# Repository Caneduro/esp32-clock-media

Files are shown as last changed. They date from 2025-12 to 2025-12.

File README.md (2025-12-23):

## **Tiny Wi-Fi Clock / Media Display**
   A compact 3D-printed desk gadget that displays the time or, with a press of the **on-board BOOT button**, switches to show your PC’s current media activity (received via Wi-Fi from a small Python script).\
   The enclosure is printed in **three PLA parts** (front, middle, back) assembled with **heat inserts and screws** for a solid, serviceable build.\
   It prints in about **1 hour** and uses only **~14 g of PLA** — perfect for a quick and satisfying build.
   ### **Features**
- 🕒 Clean, high-contrast oled **time** display
- 🎵 **Media** mode with track info, progress, duration, play/pause status, volume, scrolling if text too long
- 📡 Wi-Fi6 communication with a simple Python script on your PC
- 🔘 Uses the **on-board BOOT button** — no external switch needed 
- 🧱 3-part enclosure with heat inserts + M2 screws
- ⚡ USB type C connection 
### **Print Details**
- 🧵 **Material:** PLA (~14 g)
- ⏱ **Print time:** ~1 hour
- 🧩 **Included 3MF parts:** front (screen cover), middle (electronics housing), rear
### **Bill of Materials**
Here are the exact components used in the build:

- 🔌 **ESP32-C6 SuperMini development board (USB-C)**\
  [https://it.aliexpress.com/item/1005009279209835.html](https://it.aliexpress.com/item/1005009279209835.html)
- 🖥️ **128×64 0.96″ monochrome white OLED display**\
  [https://it.aliexpress.com/item/1005006141235306.html](https://it.aliexpress.com/item/1005006141235306.html)
- 🔩 **M2 brass heat inserts + M2 screws** \
  [https://it.aliexpress.com/item/1005007615031481.html](https://it.aliexpress.com/item/1005007615031481.html)
- 📌 **Solder-pin headers (to connect the OLED via jumper wires)**\
  [https://it.aliexpress.com/item/4000875355189.html](https://it.aliexpress.com/item/4000875355189.html)
- 🧵 **Female-to-female jumper cables**\
  [https://it.aliexpress.com/item/1005003641187997.html](https://it.aliexpress.com/item/1005003641187997.html)

## **How to Flash the Code to the ESP32-C6 SuperMini**
Follow these steps to upload the firmware to your ESP32-C6 using the Arduino IDE.
### **🔧 1. Install the required tools**
1. Download and install the **Arduino IDE** (version 2.x recommended).
1. Open the IDE, go to **File → Preferences**.
1. In *Additional Boards Manager URLs*, add this URL (if not already present):

*`https://raw.githubusercontent.com/espressif/arduino-esp32/gh-pages/package_esp32_index.json`*

1. Go to **Tools → Board → Boards Manager** and search for:\
   **“ESP32 by Espressif Systems”**\
   → Install it (or update to the latest version).
1. Install any required libraries for your project (e.g. WiFi, SSD1306 display, etc., depending on your code, they are usually on top).
### **🔌 2. Connect the ESP32-C6 to your PC**
- Plug the board into your computer using a **USB-C cable** (ensure it’s a data cable, not charge-only).
- The board should appear as a COM/serial port or it should be recognized as ESP32 Family Device then select the appropriate device.
### **🧭 3. Select the correct board**
In Arduino IDE:

- Go to **Tools → Board → ESP32**
- Select **“ESP32C6 Dev Module”** (or “ESP32-C6 SuperMini” if shown).
### **🔌 4. Select the right serial port**
- Go to **Tools → Port**
- Choose the port labeled **ESP32C6** or the newly appeared COM port.

If you’re unsure which one is correct:

- Unplug the board → check the list
- Plug it back → choose the new entry that appears.
### **📄 5. Load your project code**
- Open the .ino file (or create a new sketch and paste your code).
- Go to **Sketch** and click **Add file…** to add the fonts **(THIS IS MANDATORY)**

- Verify that any required libraries are installed otherwise it will give out error (the error shows wich library is missing).
### **📝 6. Adjust upload settings** 
Usually the defaults work, but for ESP32-C6 ensure:

- **Tools → Upload Speed:** 115200 (safe default)
- **Tools → USB CDC On Boot:** Enabled

- **Tools → Partition Scheme: Minimal SPIFFS (otherwise ota update will not work)**
### **⬇️ 7. Put the board into bootloader mode (if required)**
Often the ESP32-C6 enters bootloader mode automatically.\
If flashing fails on the first attempt:

1. Hold **BOOT**
1. Click **RESET** (if present on your module)
1. Release **BOOT** after 1–2 seconds

Then try uploading again.

Most C6 SuperMini boards auto-reset and you won’t need this step.
### **🚀 8. Upload the code**
- Click the **Upload** button (the right-arrow icon).
- Wait for compilation and flashing to complete.
- The serial monitor will confirm a successful upload.
### **✔️ 9. Test the device**
- Open **Serial Monitor** (Tools → Serial Monitor) to check Wi-Fi logs or debug messages.
- If using your BOOT button to toggle modes, verify it responds correctly once the device is running., 

### **BUILDING INSTRUCTIONS**

- Print the the file (1 part at a time or all at once as you prefer)

- use your preferred method to put all the heat inserts: 
  - face: M2 x 3mm         - screw: M2 x 7mm (at least more than 3mm)
  - rear: M2 x 2mm         - screw: M2 x 6mm (at least more than 2mm)

- solder 4 header pins (gnd - 3v3 - 20 -19) 

- connect to screen with jumper cables: 

   - gnd with gnd

   - 3v3 with 3v3 

   - pin 20 with SCK

   - pin 19 with SDA

- "coil" the cable to fit all inside the enclosure

- put the screen over the holes from the front and put the face 3d printed part over it then screw them to keep it in place

- put the rear cover and screw it in place 

**FULLY OPEN-SOURCE\
All required files — firmware, the Python script, and all 3D models — are available on GitHub:\
👉 https://github.com/caneduro/esp32-clock-media**
----------------------------------------------------------------------------------------------
The project is fully **open-source**.\
Anyone can fork it, modify it, improve it, or contribute.\
The current version is not 100% complete and can definitely be refined by someone with more experience — contributions are welcome!
BTW right now all the text are in italian, so you need to change them to be your language + YOU NEED TO CHANGE WIFI CREDENTIALS OTHERWISE IT WON'T WORK AND OTA (if you need to)

3D model view
3D view

Front view with clock
clock front view

Front view witch media
media front view

Back internal view
Back hollow

Internal view
Internal view

ToDo list
- [x] Update Python code to fix volume and postition (Note: when changing volume the song position may change temporarily idky)
- [ ] Update C code to implement WiFi captive portal to connect instead of hardcoded wifi ssid and password
- [ ] Add small clock on top of the Media mode (maybe with some animation changing from clock to media and vice versa) (so you could have clock on media mode but idk if the single core ESP32C6 could handle it)
- [ ] Improve reactivity of the infos on Media mode (python side i think)
- [ ] Think about adding a battery inside the casing or maybe another "battery module" that could be added behind with usb c
- [ ] switch from screws and heat inserts to small magnets (maybe???)

If you want to help, you can talk to me on my discord
[discordhereeee!!!](https://discord.gg/QAPAbSd2Ep)

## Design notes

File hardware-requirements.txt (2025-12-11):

ESP32-C6 Supermini dev board usb C
4 solder pins (used to connect the screen with cables to the esp32)
8 brass heat insert 
8 screws:
			face: M2 x 3mm 		screw: M2 x 7mm (at least more than 3mm)
			rear: M2 x 2mm 		screw: M2 x 6mm (at least more than 2mm)	
1,5mm Hex Key (to screw in the screws, you can also use the one wich comes with your 3d printer like A1 mini etc.. lol)			
1 OLED SCREEN 128x64 px (i used an all white pixel one)
4 dupont female-female cables (i used 10cm but i think less would be better) 
13g of PLA and around 1H of your time ;)

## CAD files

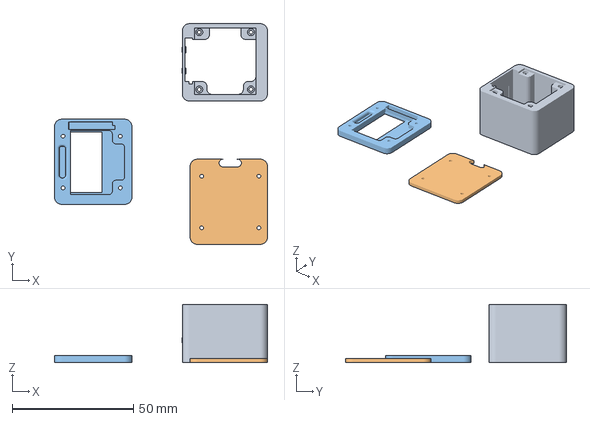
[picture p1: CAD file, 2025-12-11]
MINI Esp32 usb clock v9.3mf
88.0 x 91.2 x 24.1 mm
Corpo2
Corpo1 x 2

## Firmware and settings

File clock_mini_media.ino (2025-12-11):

// merged_clock_media_button_idle_auto_switch_fixed.ino
// Merge: clock (Adafruit) + media (U8g2).
// Fix: scrolling bug, robust manual toggle after auto-switch, reset media to defaults in a function.

#include <WiFi.h>
#include <NTPClient.h>
#include <WiFiUdp.h>

#include <Wire.h>
#include <Adafruit_GFX.h>
#include <Adafruit_SSD1306.h>

#include <U8g2lib.h>

#include <WebServer.h>
#include <ArduinoJson.h>

#include "unifont_custom.h" 

#include <ArduinoOTA.h>
//#include <ElegantOTA.h>


// -------------------- CONFIG --------------------
#define SCREEN_WIDTH 128
#define SCREEN_HEIGHT 64
#define OLED_SDA 19
#define OLED_SCL 20

U8G2_SSD1306_128X64_NONAME_F_HW_I2C u8g2(U8G2_R0, U8X8_PIN_NONE);
Adafruit_SSD1306 display(SCREEN_WIDTH, SCREEN_HEIGHT, &Wire, -1);

const char* ssid = "YOURWIFI";
const char* password = "YOURPASSWORD";
WiFiUDP ntpUDP;
NTPClient timeClient(ntpUDP, "pool.ntp.org", 3600, 60000);

WebServer server(80);

const char* otahostname = "ESP32-OTA";
const char* otapassword = "yourpassword";

// Debug
const bool DEBUG_SERIAL = false;

// -------------------- CLOCK (Adafruit) resources --------------------
#include <Fonts/FreeSans9pt7b.h>
#include <Fonts/FreeSans12pt7b.h>
#include <Fonts/FreeSans18pt7b.h>
#include <Fonts/FreeSans24pt7b.h>
#include <Fonts/FreeSansBold9pt7b.h>
#include <Fonts/FreeSansBold12pt7b.h>
#include <Fonts/FreeSansBold18pt7b.h>
#include <Fonts/FreeSansBold24pt7b.h>
#include <Fonts/FreeSerif9pt7b.h>
#include <Fonts/FreeSerif12pt7b.h>
#include <Fonts/FreeSerif18pt7b.h>
#include <Fonts/FreeSerif24pt7b.h>
#include <Fonts/FreeMono9pt7b.h>
#include <Fonts/FreeMono12pt7b.h>
#include <Fonts/FreeMono18pt7b.h>
#include <Fonts/FreeMono24pt7b.h>

const char* giorniArr[] = {"dom", "lun", "mar", "mer", "gio", "ven", "sab"};
const char* mesiArr[]  = {"gen","feb","mar","apr","mag","giu","lug","ago","set","ott","nov","dic"};

const GFXfont* fontsArr[] = {
  nullptr,
  &FreeSans9pt7b, &FreeSans12pt7b, &FreeSans18pt7b, &FreeSans24pt7b,
  &FreeSansBold9pt7b, &FreeSansBold12pt7b, &FreeSansBold18pt7b, &FreeSansBold24pt7b,
  &FreeSerif9pt7b, &FreeSerif12pt7b, &FreeSerif18pt7b, &FreeSerif24pt7b,
  &FreeMono9pt7b, &FreeMono12pt7b, &FreeMono18pt7b, &FreeMono24pt7b
};
const int numFonts = sizeof(fontsArr) / sizeof(fontsArr[0]);

int fontOrologio = 8;
int fontSecondi  = 0;
int fontData     = 0;
int dimensioneOrologio = 4;
int dimensioneSecondi  = 1;
int dimensioneData     = 1;

int posizioneYOrologio = 35;
int posizioneYSecondi  = 39;
int posizioneYData     = SCREEN_HEIGHT - 12;

unsigned long lastSecond = 0;
unsigned long lastWifiAttempt = 0;
bool wifiConnected = false;
const unsigned long wifiRetryInterval = 400; // ms

// clock state
int hours = 0;
int minutes = 0;
int seconds = 0;
int day = 1;
int month = 1;
int year = 1970;
int dayOfWeek = 4;

// -------------------- MEDIA (U8g2) resources --------------------
const char* HOST_PATH = "/update";
#define USE_CUSTOM_UNIFONT 1
#define CUSTOM_UNIFONT_SYMBOL unifont_custom
#define USE_UNIFONT_FOR_POSITION 1
#define USE_UNIFONT_FOR_VOLUME   1

const int GAP_PIXELS = 30;
const unsigned long SCROLL_STEP_MS = 30;

String mediaTitle = "Nessun titolo";
String mediaArtist = "Nessun artista";
String mediaStatus = "PAUSE";

float serverPosition = 0.0f;
float displayPosition = 0.0f;
float mediaDuration = 0.0f;
unsigned long lastServerMillis = 0;

float mediaProgress = 0.0f;
float targetProgress = 0.0f;
float mediaVolume = 0.0f;
float targetVolume = 0.0f;

int scrollOffsetTitle = 0;
int scrollOffsetArtist = 0;
unsigned long lastScrollMs = 0; 

const int ICON_W = 18;
const int TEXT_AREA_X = ICON_W + 2;
const int TEXT_AREA_RIGHT_MARGIN = 12;
const int TEXT_AREA_W = 128 - TEXT_AREA_X - TEXT_AREA_RIGHT_MARGIN;

const float staleThreshold = 0.5f;
const float seekThreshold  = 1.0f;

// -------------------- MODE / BUTTON --------------------
#define BOOT_BUTTON_PIN 9
enum Mode { MODE_MEDIA=0, MODE_CLOCK=1 };
volatile Mode currentMode = MODE_CLOCK;

// ISR flag + guard
volatile bool buttonISRflag = false;
unsigned long lastToggleMillis = 0;
const unsigned long TOGGLE_GUARD_MS = 200;

// -------------------- IDLE/AUTO-SWITCH --------------------
const unsigned long MEDIA_IDLE_TIMEOUT_MS_DEFAULT = 5UL * 60UL * 1000UL; // 5 minutes
unsigned long MEDIA_IDLE_TIMEOUT_MS = MEDIA_IDLE_TIMEOUT_MS_DEFAULT;

// last time we had media activity (update received, position advanced, volume changed...)
// initialized in setup
unsigned long lastMediaActiveMs = 0;

// to detect movement
float prevDisplayPosition = -1.0f;
const float MOVEMENT_EPS = 0.25f; // seconds movement threshold to consider "activity"

// protect auto-switch briefly after manual toggle so user can open MEDIA without instant re-auto-switch
unsigned long manualProtectUntil = 0;
const unsigned long MANUAL_PROTECT_MS = 2000UL; // 2 seconds

// -------------------- HELPERS --------------------
String formatTimeMMSS(int secondsVal){
  int m = secondsVal / 60;
  int s = secondsVal % 60;
  char buf[16];
  snprintf(buf, sizeof(buf), "%02d:%02d", m, s);
  return String(buf);
}

// reset media values in one place (reusable)
void resetMediaStateToDefaults(bool keepLastMediaActive = false){
  mediaTitle = "Nessun titolo";
  mediaArtist = "Nessun artista";
  mediaStatus = "PAUSE";
  serverPosition = 0.0f;
  displayPosition = 0.0f;
  mediaDuration = 0.0f;
  lastServerMillis = millis();
  mediaProgress = 0.0f;
  targetProgress = 0.0f;
  mediaVolume = 0.0f;
  targetVolume = 0.0f;
  scrollOffsetTitle = 0;
  scrollOffsetArtist = 0;
  prevDisplayPosition = -1.0f;
  if (!keepLastMediaActive) {
    // caller decides whether to update lastMediaActiveMs
    // normally when auto-switching we won't preserve lastMediaActive
  }
}

// -------------------- CLOCK (Adafruit) functions --------------------
void impostaFontClock(int fontIndex, int dimensione) {
  if (fontIndex >= 0 && fontIndex < numFonts) {
    if (fontsArr[fontIndex] == nullptr) {
      display.setFont(); // default
      display.setTextSize(dimensione);
    } else {
      display.setFont(fontsArr[fontIndex]);
      display.setTextSize(1);
    }
  } else {
    display.setFont();
    display.setTextSize(dimensione);
  }
}

void updateDisplayClock(){
  display.clearDisplay();

  impostaFontClock(fontOrologio, dimensioneOrologio);
  String timeStr = (hours < 10 ? "0" : "") + String(hours) + ":" + (minutes < 10 ? "0" : "") + String(minutes);

  int16_t x1,y1; uint16_t w,h;
  display.getTextBounds(timeStr, 0, 0, &x1, &y1, &w, &h);
  int xTime = (SCREEN_WIDTH - w) / 2;
  display.setCursor(xTime, posizioneYOrologio);
  display.setTextColor(WHITE);
  display.print(timeStr);

  // secondi
  impostaFontClock(fontSecondi, dimensioneSecondi);
  String secStr = (seconds < 10 ? "0" : "") + String(seconds);
  display.getTextBounds(secStr, 0, 0, &x1, &y1, &w, &h);
  display.setCursor(SCREEN_WIDTH - w - 2, posizioneYSecondi);
  display.print(secStr);

  // data
  impostaFontClock(fontData, dimensioneData);
  String dataStr = String(giorniArr[dayOfWeek]) + " " + String(day) + " " + String(mesiArr[month-1]) + " " + String(year);
  display.getTextBounds(dataStr, 0, 0, &x1, &y1, &w, &h);
  int xData = (SCREEN_WIDTH - w) / 2;
  display.setCursor(xData, posizioneYData);
  display.print(dataStr);

  // linea separatrice
  display.drawLine(0, SCREEN_HEIGHT - 15, SCREEN_WIDTH, SCREEN_HEIGHT - 15, WHITE);

  display.display();

  if (DEBUG_SERIAL) {
    Serial.print("[DEBUG] Clock draw: ");
    Serial.print(timeStr); Serial.print(" "); Serial.println(dataStr);
  }
}

// -------------------- MEDIA (U8g2) functions --------------------
void drawStateIcon_u8(){
  const int x = 0, y = 0, w = ICON_W, h = 18;
  u8g2.setDrawColor(0);
  u8g2.drawBox(x,y,w,h);
  u8g2.setDrawColor(1);
  if(mediaStatus == "PLAY"){
    int x1 = x+4, y1 = y+3;
    int x2 = x+4, y2 = y+15;
    int x3 = x+14, y3 = y+9;
    u8g2.drawTriangle(x1,y1,x2,y2,x3,y3);
  } else {
    int barW=3,gap=4,bx=x+4,by=y+3,bh=12;
    u8g2.drawBox(bx,by,barW,bh);
    u8g2.drawBox(bx+barW+gap,by,barW,bh);
  }
}

void drawVolume_u8(){
  int barWidth=6, barHeight=16, barX=128-barWidth, barY=0;
  u8g2.setDrawColor(0);
  u8g2.drawBox(barX,barY,barWidth,barHeight);
  u8g2.setDrawColor(1);
  int volHeight = (int)constrain((mediaVolume/100.0f)*barHeight, 0, barHeight);
  u8g2.drawFrame(barX,barY,barWidth,barHeight);
  u8g2.drawBox(barX, barY + barHeight - volHeight, barWidth, volHeight);
  if(USE_UNIFONT_FOR_VOLUME) u8g2.setFont(CUSTOM_UNIFONT_SYMBOL);
  else u8g2.setFont(u8g2_font_6x10_tr);
  String volStr = String((int)(mediaVolume + 0.5f));
  int numW = u8g2.getUTF8Width(volStr.c_str());
  int xOffset = barX - numW - 2;
  int yOffset = USE_UNIFONT_FOR_VOLUME ? (10 + 6) : ((barHeight - 6) / 2 + 6);
  u8g2.drawUTF8(xOffset, yOffset, volStr.c_str());
}

void drawProgressBar_u8(){
  int barWfilled = (int)((mediaProgress / 100.0f) * 128.0f);
  barWfilled = constrain(barWfilled, 0, 128);
  u8g2.setDrawColor(1);
  u8g2.drawBox(0, 64 - 8, barWfilled, 4);
  u8g2.drawFrame(0, 64 - 8, 128, 4);
  if(USE_UNIFONT_FOR_POSITION) u8g2.setFont(CUSTOM_UNIFONT_SYMBOL);
  else u8g2.setFont(u8g2_font_6x10_tr);
  u8g2.drawUTF8(0, 64 - 16 + 6, formatTimeMMSS((int)displayPosition).c_str());
  String tot = formatTimeMMSS((int)mediaDuration);
  int len = u8g2.getUTF8Width(tot.c_str());
  u8g2.drawUTF8(128 - len, 64 - 16 + 6, tot.c_str());
}

void drawScrollingUTF8_u8(const String &txt, int baselineY, int areaX, int areaW, int &offset){
  const char* s = txt.c_str();
#if USE_CUSTOM_UNIFONT
  u8g2.setFont(CUSTOM_UNIFONT_SYMBOL);
#else
  u8g2.setFont(u8g2_font_unifont_t_symbols);
#endif
  uint16_t textW = u8g2.getUTF8Width(s);
  if(textW <= (uint16_t)areaW){
    u8g2.drawUTF8(areaX, baselineY, s);
    offset = 0;
  } else {
    int total = textW + GAP_PIXELS;
    int x1 = areaX - offset;
    int x2 = x1 + total;
    u8g2.drawUTF8(x1, baselineY, s);
    u8g2.drawUTF8(x2, baselineY, s);
  }
}

void updateDisplayMedia(){
  u8g2.clearBuffer();
  drawStateIcon_u8();
  drawVolume_u8();
  int titleBaseline = 27;
  int artistBaseline = 41;
  drawScrollingUTF8_u8(mediaTitle, titleBaseline, TEXT_AREA_X, TEXT_AREA_W, scrollOffsetTitle);
  drawScrollingUTF8_u8(mediaArtist, artistBaseline, TEXT_AREA_X, TEXT_AREA_W, scrollOffsetArtist);
  drawProgressBar_u8();
  u8g2.sendBuffer();
}

// scrollTick_u8 is now self-contained: it updates lastScrollMs and offsets
void scrollTick_u8(){
  unsigned long now = millis();
  if(now - lastScrollMs < SCROLL_STEP_MS) return;
  lastScrollMs = now;

#if USE_CUSTOM_UNIFONT
  u8g2.setFont(CUSTOM_UNIFONT_SYMBOL);
#else
  u8g2.setFont(u8g2_font_unifont_t_symbols);
#endif

  uint16_t wTitle = u8g2.getUTF8Width(mediaTitle.c_str());
  if(wTitle > (uint16_t)TEXT_AREA_W){
    int total = wTitle + GAP_PIXELS;
    scrollOffsetTitle++;
    if(scrollOffsetTitle >= total) scrollOffsetTitle = 0;
  } else scrollOffsetTitle = 0;

  uint16_t wArtist = u8g2.getUTF8Width(mediaArtist.c_str());
  if(wArtist > (uint16_t)TEXT_AREA_W){
    int total = wArtist + GAP_PIXELS;
    scrollOffsetArtist++;
    if(scrollOffsetArtist >= total) scrollOffsetArtist = 0;
  } else scrollOffsetArtist = 0;
}

// -------------------- MEDIA HTTP handler --------------------
void handleMediaUpdate(){
  if(DEBUG_SERIAL) Serial.println("[DEBUG] Received /update request");
  if(!server.hasArg("plain")){
    server.send(400, "application/json", "{\"status\":\"no body\"}");
    if(DEBUG_SERIAL) Serial.println("[DEBUG] No body in request");
    return;
  }
  String body = server.arg("plain");
  if(DEBUG_SERIAL){
    Serial.print("[DEBUG] Body: ");
    Serial.println(body);
  }

  JsonDocument doc;
  DeserializationError error = deserializeJson(doc, body);
  if(error){
    server.send(400, "application/json", "{\"status\":\"json error\"}");
    if(DEBUG_SERIAL) {
      Serial.print("[DEBUG] JSON parse error: ");
      Serial.println(error.c_str());
    }
    return;
  }

  String newTitle = doc["title"] | "Sconosciuto";
  String newArtist = doc["artist"] | "Sconosciuto";
  String newStatus = doc["status"] | "PAUSE";

  // normalize artists (basic)
  newArtist.replace(";", ",");
  newArtist.replace("|", ",");
  newArtist.replace("/", ",");
  while (newArtist.indexOf(",,") != -1) newArtist.replace(",,", ",");
  newArtist.replace(", ", ",");
  newArtist.replace(" ,", ",");
  newArtist.trim();

  float newPosition = 0.0f;
  float newDuration = 0.0f;
  int newVolume = -1;

  if (!doc["position"].isNull()) {
    newPosition = (float)doc["position"].as<double>();
  }
  if (!doc["duration"].isNull()) {
    newDuration = (float)doc["duration"].as<double>();
  }
  if (!doc["volume"].isNull()) {
    newVolume = doc["volume"].as<int>();
  }

  bool changed = false;
  unsigned long now = millis();

  // any received update is media activity -> reset idle timer
  lastMediaActiveMs = now;

  bool titleArtistChanged = (newTitle != mediaTitle) || (newArtist != mediaArtist);
  bool durationChanged = fabs(newDuration - mediaDuration) > 0.5f;

  if(titleArtistChanged || durationChanged){
    mediaTitle = newTitle;
    mediaArtist = newArtist;
    mediaDuration = newDuration;
    serverPosition = newPosition;
    lastServerMillis = now;
    displayPosition = serverPosition;
    targetProgress = (mediaDuration > 0.0f) ? (displayPosition * 100.0f / mediaDuration) : 0.0f;
    mediaProgress = targetProgress;
    mediaStatus = newStatus;
    if(newVolume >= 0) { targetVolume = (float)newVolume; mediaVolume = targetVolume; }
    scrollOffsetTitle = 0;
    scrollOffsetArtist = 0;
    changed = true;
  } else {
    if(newStatus != mediaStatus){ mediaStatus = newStatus; changed = true; }
    if(newTitle != mediaTitle || newArtist != mediaArtist){ mediaTitle = newTitle; mediaArtist = newArtist; changed = true; }

    if (mediaStatus == "PLAY") {
      float currentEstimate = serverPosition + ((now - lastServerMillis) / 1000.0f);
      float diff = newPosition - currentEstimate;
      if (fabs(diff) >= seekThreshold) {
        serverPosition = newPosition;
        lastServerMillis = now;
        changed = true;
      } else if (newPosition >= currentEstimate - staleThreshold) {
        serverPosition = newPosition;
        lastServerMillis = now;
        changed = true;
      } else {
        serverPosition = currentEstimate;
        lastServerMillis = now;
      }
    } else {
      serverPosition = newPosition;
      lastServerMillis = now;
      changed = true;
    }

    if (fabs(newDuration - mediaDuration) > 0.0001f) {
      mediaDuration = newDuration;
      changed = true;
    }

    // update volume even if title is default (fix missing volume update)
    if(newVolume >= 0 && newVolume != (int)targetVolume){
      targetVolume = (float)newVolume;
      changed = true;
    }
  }

  if(changed && currentMode == MODE_MEDIA) updateDisplayMedia();

  server.send(200, "application/json", "{\"status\":\"ok\"}");
  if(DEBUG_SERIAL) Serial.println("[DEBUG] /update processed, status ok");
}


//----------------------ota setup ------------------------------
void OTASetup(){ 
    ArduinoOTA.setHostname(otahostname);
    ArduinoOTA.setPassword(otapassword);
    ArduinoOTA
      .onStart([]() {
        String type;
        if (ArduinoOTA.getCommand() == U_FLASH)
         type = "sketch";
        else
          type = "filesystem";
       Serial.println("[OTA] Start updating " + type);
      })
      .onEnd([]() {
        Serial.println("\n[OTA] End");
      })
      .onProgress([](unsigned int progress, unsigned int total) {
        Serial.printf("[OTA] Progress: %u%%\r", (progress / (total / 100)));
      })
      .onError([](ota_error_t error) {
        Serial.printf("[OTA] Error[%u]: ", error);
        if (error == OTA_AUTH_ERROR) Serial.println("Auth Failed");
        else if (error == OTA_BEGIN_ERROR) Serial.println("Begin Failed");
        else if (error == OTA_CONNECT_ERROR) Serial.println("Connect Failed");
        else if (error == OTA_RECEIVE_ERROR) Serial.println("Receive Failed");
        else if (error == OTA_END_ERROR) Serial.println("End Failed");
      });
    
      ArduinoOTA.begin();
      //Serial.println("[OTA] Ready: access via http://" + WiFi.localIP().toString() + "/otaupdate");       //used for elegantOT, not in use right now
}

// -------------------- WiFi/NTP helpers --------------------
void connectToWiFi(){
  if(DEBUG_SERIAL) Serial.println("Tentativo di connessione WiFi...");
  //WiFi.setAutoReconnect(true);  i don't think it is needed??
  //WiFi.persistent(true);        i don't think it is needed??
  WiFi.begin(ssid, password);


  unsigned long startTime = millis();
  while (WiFi.status() != WL_CONNECTED && millis() - startTime < 1600) {
    delay(200);
    Serial.print(".");
  }

  if (WiFi.status() == WL_CONNECTED) {
    if(DEBUG_SERIAL){
      Serial.println("\Wi-Fi Connected!");
      Serial.print("IP address: ");
      Serial.println(WiFi.localIP());
    }
    wifiConnected = true;
    timeClient.begin();
  } else {
    if(DEBUG_SERIAL) Serial.println("\nWi-Fi connection failed!");
    wifiConnected = false;
  }
  lastWifiAttempt = millis();
}

// -------------------- Button ISR --------------------
void IRAM_ATTR bootButtonISR(){
  buttonISRflag = true;
}
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
void loop(){
  // Always service web server
  server.handleClient();

  ArduinoOTA.handle();

  unsigned long now = millis();

  // handle button ISR flag (debounced guard)
  if (buttonISRflag) {
    if (now - lastToggleMillis > TOGGLE_GUARD_MS) {
      Mode prev = currentMode;
      currentMode = (currentMode == MODE_MEDIA) ? MODE_CLOCK : MODE_MEDIA;
      lastToggleMillis = now;

      // if user manually opens MEDIA, protect from immediate auto-switch:
      if (currentMode == MODE_MEDIA) {
        lastMediaActiveMs = now; // protect for idle timeout
        prevDisplayPosition = -1.0f;
        manualProtectUntil = now + MANUAL_PROTECT_MS; // protect auto-switch briefly
        if (DEBUG_SERIAL) Serial.println("[DEBUG] Manual toggle -> set lastMediaActiveMs to now and protection");
      }

      if (DEBUG_SERIAL) {
        Serial.print("[DEBUG] Button toggled: ");
        Serial.print(prev==MODE_MEDIA ? "MEDIA" : "CLOCK");
        Serial.print(" -> ");
        Serial.println(currentMode==MODE_MEDIA ? "MEDIA" : "CLOCK");
      }

      if (currentMode == MODE_MEDIA) updateDisplayMedia();
      else updateDisplayClock();
    } else {
      if (DEBUG_SERIAL) Serial.println("[DEBUG] ISR guard: ignored");
    }
    buttonISRflag = false;
  }

  // WiFi reconnect attempt (non-blocking)
  if (!wifiConnected && (now - lastWifiAttempt > wifiRetryInterval)) {
    if (DEBUG_SERIAL) Serial.println("[DEBUG] Trying reconnect WiFi...");
    connectToWiFi();
  }

  if (currentMode == MODE_MEDIA) {
    // scroll tick: call the self-contained function (it internally throttles using lastScrollMs)
    scrollTick_u8();

    // update displayPosition estimation
    if(mediaStatus == "PLAY" && mediaDuration > 0.0f){
      float elapsed = (float)(now - lastServerMillis) / 1000.0f;
      displayPosition = serverPosition + elapsed;
      if(displayPosition > mediaDuration) displayPosition = mediaDuration;
    } else {
      displayPosition = serverPosition;
    }

    // detect movement (activity)
    if(prevDisplayPosition < 0.0f) {
      prevDisplayPosition = displayPosition;
    } else {
      if (fabs(displayPosition - prevDisplayPosition) > MOVEMENT_EPS) {
        lastMediaActiveMs = now;
      }
      prevDisplayPosition = displayPosition;
    }

    // easing updates
    targetProgress = (mediaDuration > 0.0f) ? (displayPosition * 100.0f / mediaDuration) : 0.0f;
    const float easing = 0.21f;
    mediaProgress += (targetProgress - mediaProgress) * easing;
    mediaVolume  += (targetVolume - mediaVolume) * easing;

    // throttle actual redraw to reduce CPU
    static unsigned long lastMediaDrawMs = 0;
    const unsigned long MEDIA_DRAW_MS = 16; // ~60 FPS
    if (now - lastMediaDrawMs >= MEDIA_DRAW_MS) {
      lastMediaDrawMs = now;
      updateDisplayMedia();
    }

    // AUTO-SWITCH: guard manual protection, then if no activity for configured timeout -> switch to clock
    if (now < manualProtectUntil) {
      // still in protection window after manual toggle; do NOT auto-switch
    } else {
      if ((now - lastMediaActiveMs) >= MEDIA_IDLE_TIMEOUT_MS) {
        if (currentMode == MODE_MEDIA) {
          currentMode = MODE_CLOCK;
          // reset media state to defaults (as requested)
          resetMediaStateToDefaults();
          // IMPORTANT: set lastMediaActiveMs to now so we don't immediately flip back
          lastMediaActiveMs = now;
          if (DEBUG_SERIAL) {
            Serial.println("[DEBUG] Auto-switch to CLOCK due to media idle. Media state reset to defaults.");
          }
          updateDisplayClock();
        }
      }
    }

  } else {
    // CLOCK mode - update at most once per second
    static unsigned long lastClockDrawMs = 0;
    if (wifiConnected) {
      timeClient.update(); // lightweight
      if (now - lastClockDrawMs >= 1000) {
        lastClockDrawMs = now;
        hours = timeClient.getHours();
        minutes = timeClient.getMinutes();
        seconds = timeClient.getSeconds();
        time_t epochTime = timeClient.getEpochTime();
        struct tm *ptm = gmtime((time_t *)&epochTime);
        day = ptm->tm_mday; month = ptm->tm_mon + 1; year = ptm->tm_year + 1900; dayOfWeek = ptm->tm_wday;
        updateDisplayClock();
      }
    } else {
      if (now - lastSecond >= 1000) {
        lastSecond = now;
        seconds++;
        if (seconds >= 60) { seconds = 0; minutes++; if (minutes >= 60) { minutes = 0; hours = (hours + 1) % 24; } }
        updateDisplayClock();
      }
    }
  }

  // yield to WiFi stack / background tasks (ESP32 / Arduino): keeps WiFi & RTOS happy
  // On ESP32 this is the recommended lightweight way to let background tasks run.
  yield();
}
